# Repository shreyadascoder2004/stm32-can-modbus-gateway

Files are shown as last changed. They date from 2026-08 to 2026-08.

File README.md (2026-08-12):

# STM32 CAN–Modbus Industrial Gateway

A 4-layer STM32-based industrial protocol gateway that bridges RS-485/Modbus-RTU
networks with CAN bus networks — designed end-to-end from schematic to PCB layout
in KiCad, with C firmware handling real-time protocol translation.

## Why this exists

Industrial factory floors often run a mix of legacy RS-485/Modbus-RTU equipment
(sensors, PLCs, HMIs) and newer CAN-based nodes (motor controllers, automotive-grade
modules). This gateway lets a Modbus master (PC, PLC, SCADA system) read and write
values on CAN-based devices without either side needing to natively support the
other's protocol — the same role commercial gateways (e.g. Moxa, Advantech) fill
in real deployments.

## How it works

1. A Modbus master sends a request (Read Holding Registers / Write Single Register)
   over RS-485
2. The STM32 receives it via UART, validates the frame (CRC16), and parses the
   register address and value
3. A lookup table maps the Modbus register to a CAN ID
4. The STM32 sends the corresponding CAN frame onto the bus
5. A CAN node responds; the STM32 receives it, maps it back to a Modbus register,
   and replies to the master over RS-485

USB is reserved for local configuration/debug access.

## Hardware

- **MCU**: STM32F407VET6 (LQFP100)
- **Power**: 24V DC input → TPS54233 buck (5V) → AP1117-33 LDO (3.3V)
- **RS-485**: MAX485E transceiver, jumper-selectable termination, fail-safe biasing
- **CAN**: SN65HVD230 transceiver, jumper-selectable 120Ω termination
- **Board**: 4-layer stackup (Signal / GND plane / 3V3 plane / Signal), designed
  in KiCad — schematic, footprint assignment, and layout completed with dedicated
  ground and power planes

See `/hardware` for the full KiCad project.

## Firmware

Written in C using the STM32 HAL, structured so the protocol logic is
hardware-independent and separately testable:

- `modbus_crc.c` — Modbus CRC16 checksum
- `modbus_parser.c` — Modbus RTU frame parsing and response building
- `can_mapping.c` — Modbus register ↔ CAN ID lookup table
- `main.c` — HAL integration: UART receive interrupt, CAN filter/notification
  setup, and the gateway's main translation loop

Clock tree: 8MHz HSE crystal → PLL → 168MHz SYSCLK, with CAN bus timing configured
for 500kbps on the 42MHz APB1 peripheral clock.

See `/firmware` for the full STM32CubeIDE project.

## Status

- Schematic: complete, ERC-clean
- PCB layout: components placed, 4-layer stackup and plane pours complete,
  routing in progress
- Firmware: compiles cleanly against the current pin mapping; logic modules
  (CRC, frame parsing, ID mapping) are hardware-independent and unit-testable
  on a PC
- Hardware validation: pending PCB fabrication and assembly — no physical
  board has been tested yet

## Build instructions

**Hardware**: open `hardware/*.kicad_pro` in KiCad 8+

**Firmware**: open `firmware/` as an existing project in STM32CubeIDE,
or import via *File → Open Projects from File System*

## License

MIT

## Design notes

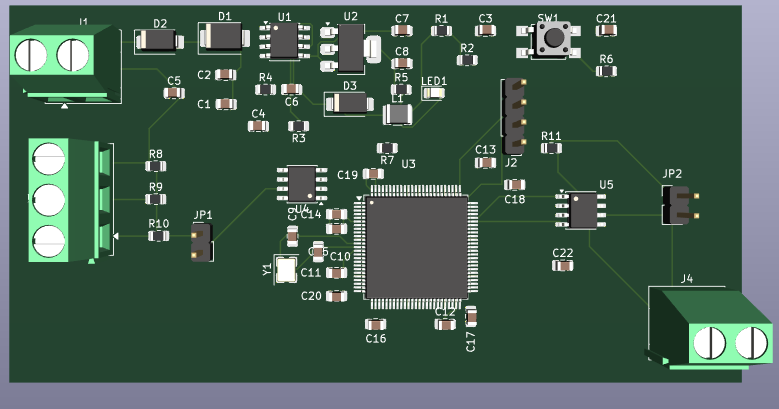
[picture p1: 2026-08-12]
Screenshot 2026-08-13 013130.png

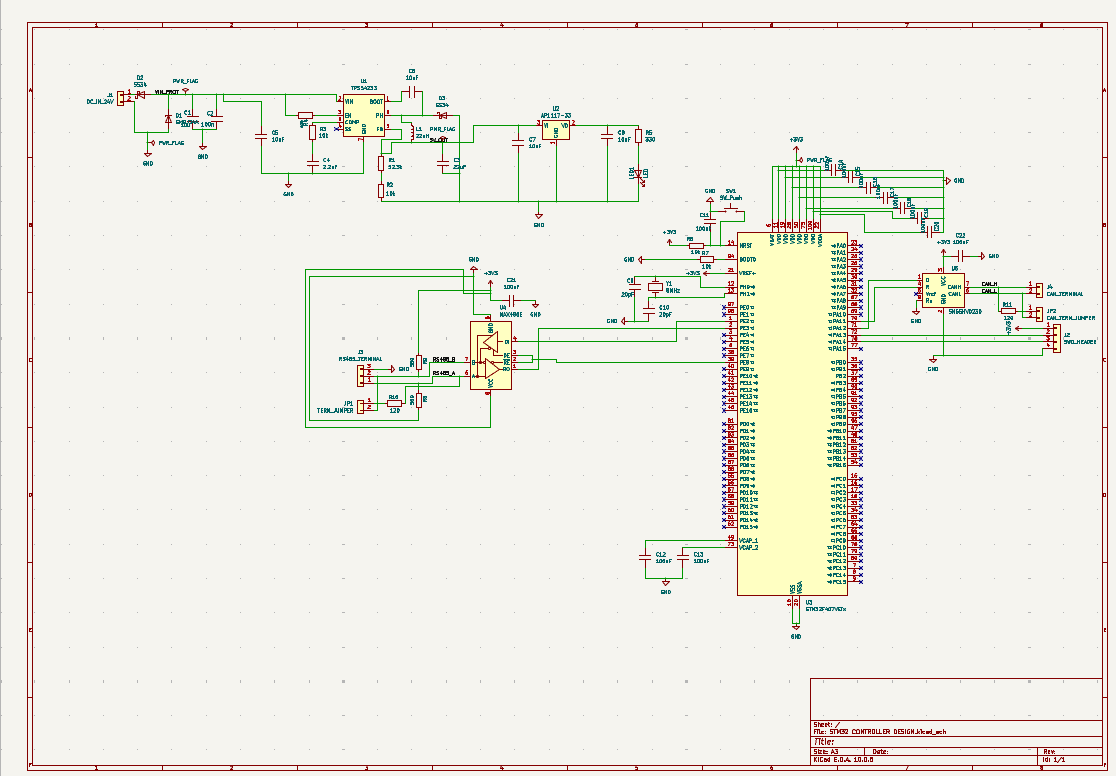
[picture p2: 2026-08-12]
Screenshot 2026-08-13 012855.png

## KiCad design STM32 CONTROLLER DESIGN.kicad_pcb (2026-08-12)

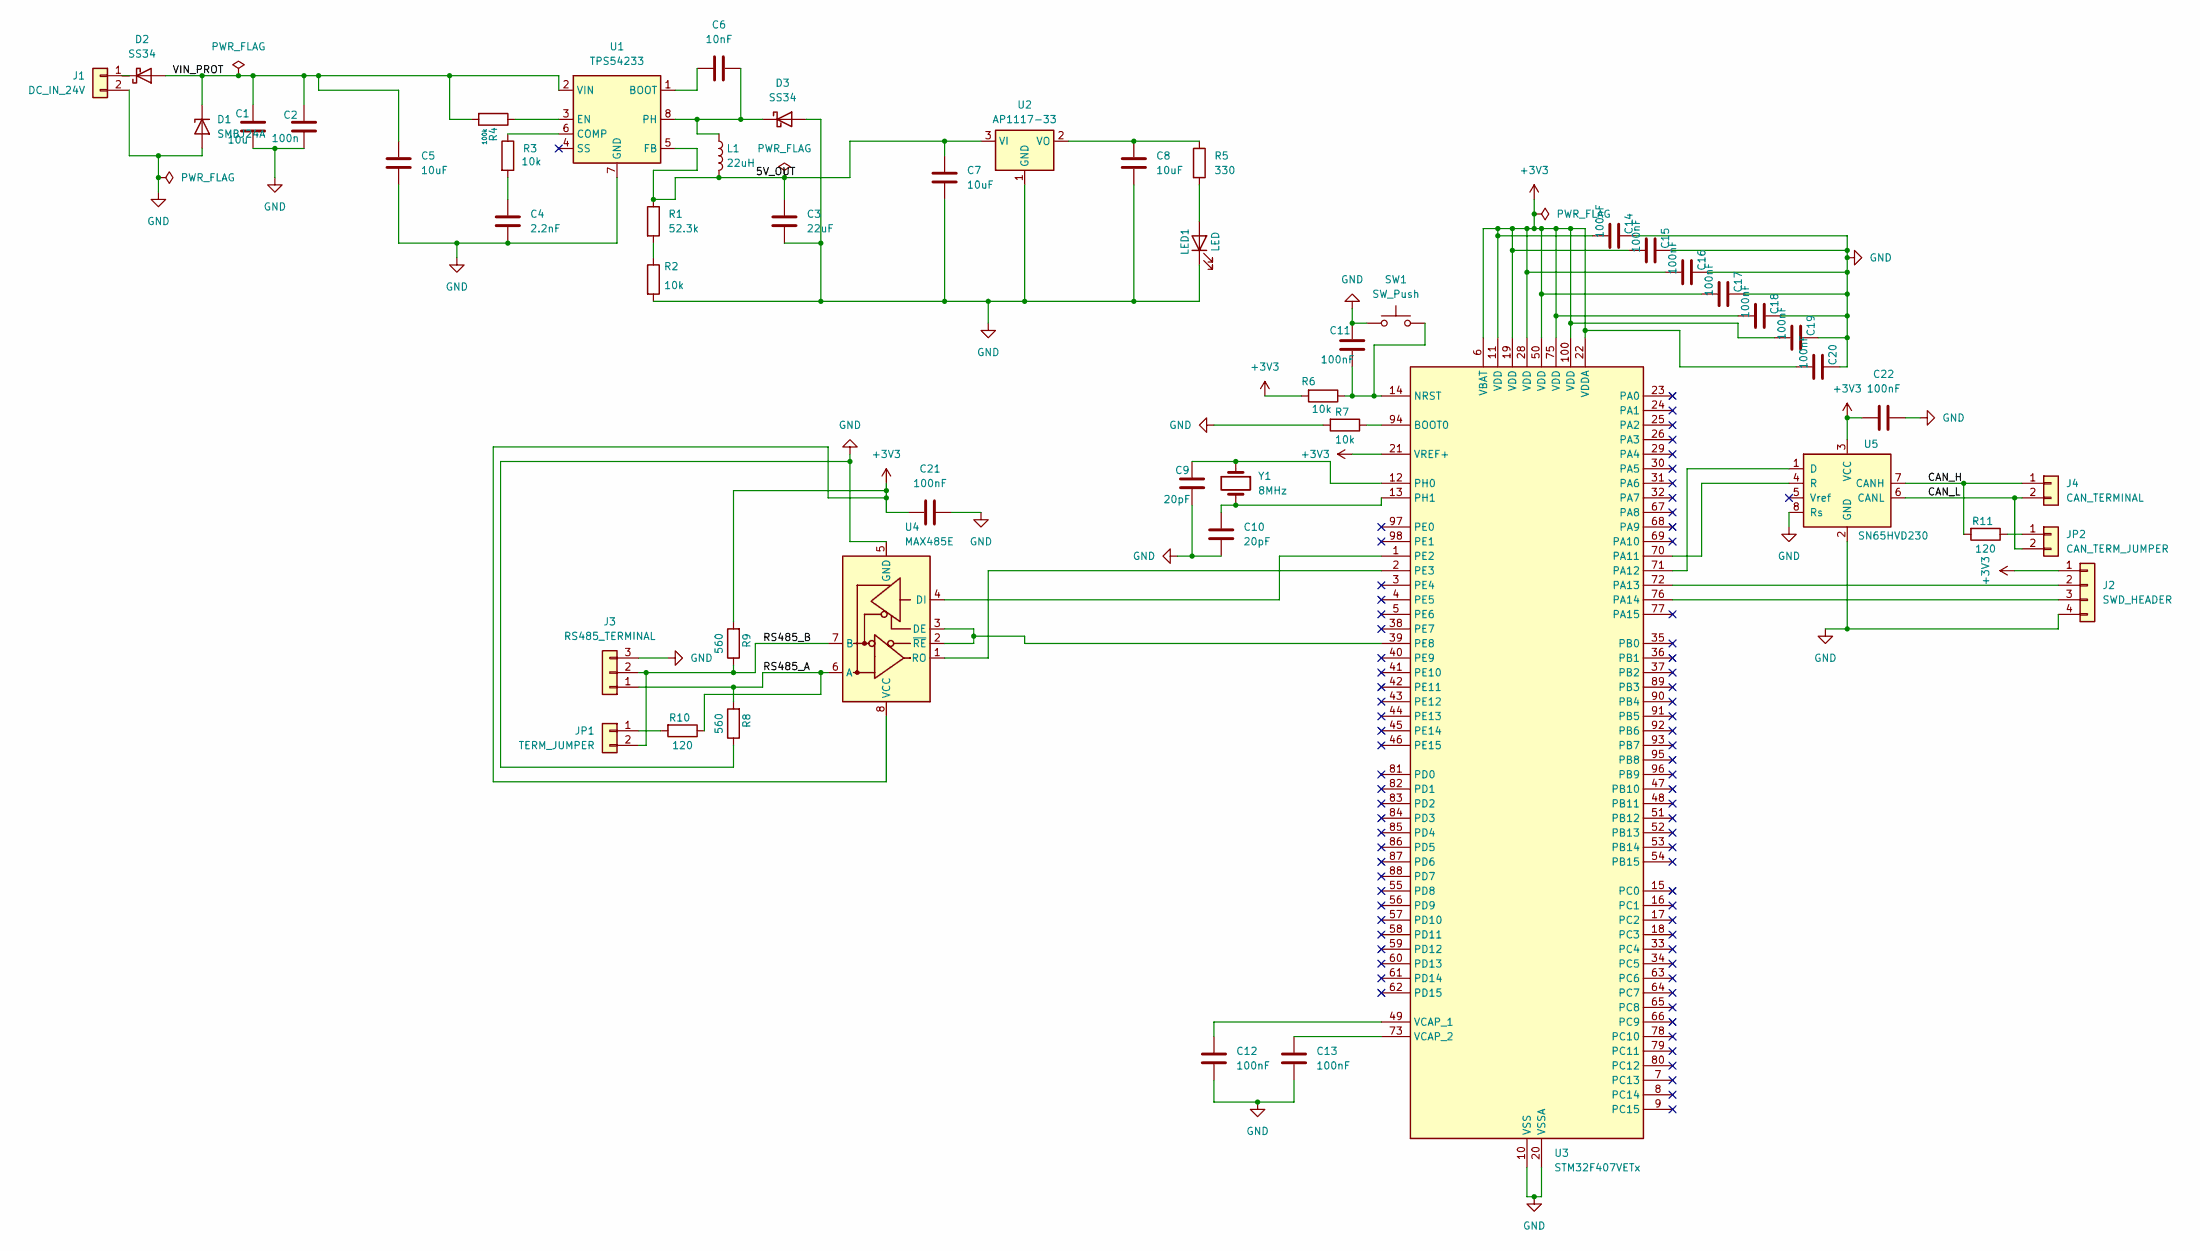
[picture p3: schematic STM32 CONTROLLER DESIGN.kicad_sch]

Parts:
C1: 10u; C_0805_2012Metric
C2: 100n; C_0805_2012Metric
C3: 22uF; C_0805_2012Metric
C4: 2.2nF; C_0805_2012Metric
C5, C7, C8: 10uF; C_0805_2012Metric
C6: 10nF; C_0805_2012Metric
C9, C10: 20pF; C_0805_2012Metric
C11, C12, C13, C14, C15, C16, C17, C18, C19, C20, C21, C22: 100nF; C_0805_2012Metric
D1: SMBJ24A; D_SMB
D2, D3: SS34; D_SMA
J1: DC_IN_24V; TerminalBlock_Phoenix_MKDS-1,5-2-5.08_1x02_P5.08mm_Horizont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
J2: SWD_HEADER; PinHeader_1x04_P2.54mm_Vertical
J3: RS485_TERMINAL; TerminalBlock_Phoenix_MKDS-1,5-3_1x03_P5.00mm_Horizontal
J4: CAN_TERMINAL; TerminalBlock_Phoenix_MKDS-1,5-2-5.08_1x02_P5.08mm_Horizont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
JP1: TERM_JUMPER; PinHeader_1x02_P2.54mm_Vertical
JP2: CAN_TERM_JUMPER; PinHeader_1x02_P2.54mm_Vertical
L1: 22uH; L_1210_3225Metric
LED1: LED; LED_0805_2012Metric
R1: 52.3k; R_0805_2012Metric
R2, R3, R6, R7: 10k; R_0805_2012Metric
R4: 100k; R_0805_2012Metric
R5: 330; R_0805_2012Metric
R8, R9: 560; R_0805_2012Metric
R10, R11: 120; R_0805_2012Metric
SW1: SW_Push; SW_SPST_TL3305A
U1: TPS54233; SOIC-8_3.9x4.9mm_P1.27mm
U2: AP1117-33; SOT-223-3_TabPin2
U3: STM32F407VETx; LQFP-100_14x14mm_P0.5mm
U4: MAX485E; SOIC-8_3.9x4.9mm_P1.27mm
U5: SN65HVD230; SOIC-8_3.9x4.9mm_P1.27mm
Y1: 8MHz; Crystal_SMD_3225-4Pin_3.2x2.5mm

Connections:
+3V3: C14.2, C15.2, C16.2, C17.2, C18.2, C19.2, C20.2, C21.2, C22.2, J2.1, R6.2, R9.2, U3.6 (VBAT), U3.11 (VDD), U3.19 (VDD), U3.21 (VREF+), U3.22 (VDDA), U3.28 (VDD), U3.50 (VDD), U3.75 (VDD), U3.100 (VDD), U4.8 (VCC), U5.3 (VCC)
/5V_OUT: C3.1, C7.1, L1.2, R1.1, U1.5 (FB), U2.3 (VI)
/CAN_H: J4.1, R11.2, U5.7 (CANH)
/CAN_L: J4.2, JP2.2, U5.6 (CANL)
/RS485_A: J3.1, R8.2, R10.1, U4.6 (A)
/RS485_B: J3.2, JP1.2, R9.1, U4.7 (B)
/VIN_PROT: C1.1, C2.1, C5.1, D1.1 (K), D2.2 (A), R4.2, U1.2 (VIN)
GND: C1.2, C2.2, C3.2, C4.2, C5.2, C7.2, C8.2, C9.2, C10.2, C11.1, C12.2, C13.2, C14.1, C15.1, C16.1, C17.1, C18.1, C19.1, C20.1, C21.1, C22.1, D1.2 (A), D3.2 (A), J1.2, J2.4, J3.3, LED1.1 (K), R2.2, R7.2, R8.1, SW1.1, U1.7 (GND), U2.1 (GND), U3.10 (VSS), U3.20 (VSSA), U3.27 (VSS), U3.74 (VSS), U3.99 (VSS), U4.5 (GND), U5.2 (GND), U5.8 (Rs)
unnamed: C4.1, R3.2
unnamed: D2.1 (K), J1.1
unnamed: C6.1, D3.1 (K), L1.1, U1.8 (PH)
unnamed: J2.2, U3.72 (PA13)
unnamed: J2.3, U3.76 (PA14)
unnamed: JP1.1, R10.2
unnamed: JP2.1, R11.1
unnamed: LED1.2 (A), R5.2
unnamed: R1.2, R2.1
unnamed: C6.2, U1.1 (BOOT)
unnamed: R3.1, U1.6 (COMP)
unnamed: R4.1, U1.3 (EN)
unnamed: C8.1, R5.1, U2.2 (VO)
unnamed: R7.1, U3.94 (BOOT0)
unnamed: C11.2, R6.1, SW1.2, U3.14 (NRST)
unnamed: U3.70 (PA11), U5.4 (R)
unnamed: U3.71 (PA12), U5.1 (D)
unnamed: U3.1 (PE2), U4.4 (DI)
unnamed: U3.2 (PE3), U4.1 (RO)
unnamed: U3.39 (PE8), U4.2 (~RE), U4.3 (DE)
unnamed: C9.1, U3.12 (PH0), Y1.1
unnamed: C10.1, U3.13 (PH1), Y1.2
unnamed: C12.1, U3.49 (VCAP_1)
unnamed: C13.1, U3.73 (VCAP_2)

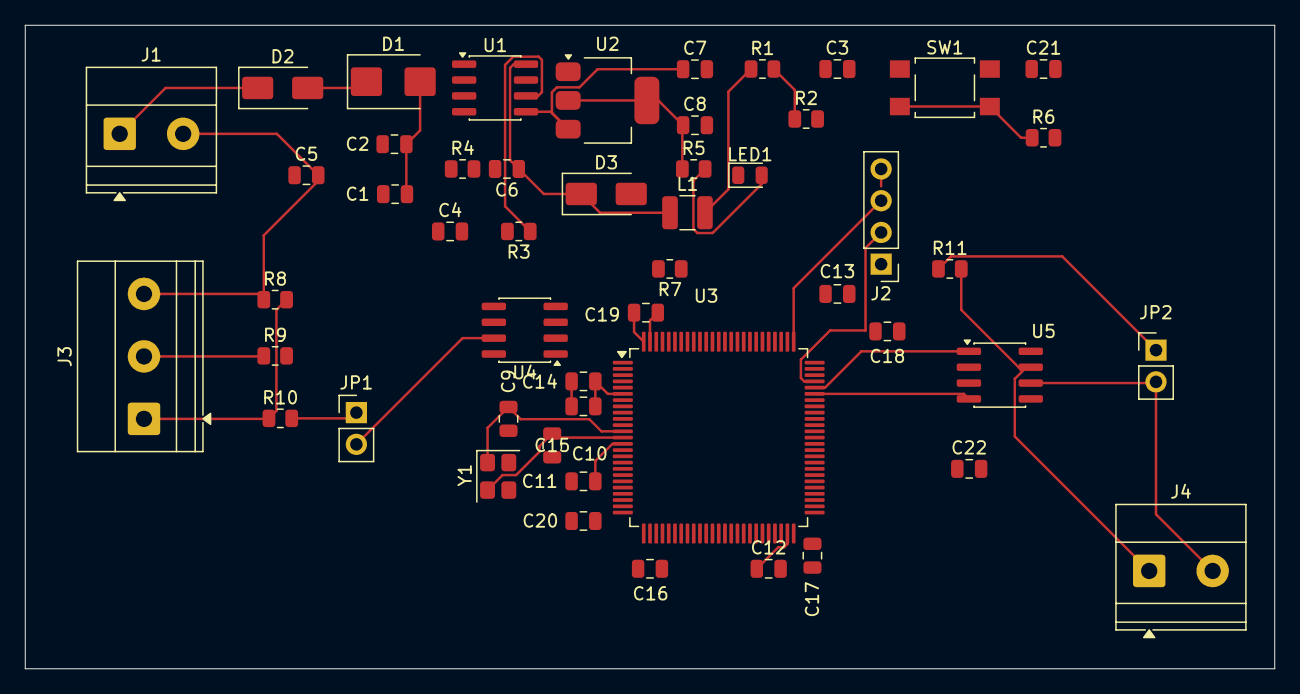
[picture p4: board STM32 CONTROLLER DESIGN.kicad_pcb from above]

Board: 4 copper layers, 100.0 x 51.5 mm, 51 parts (0 on the bottom side), 32 nets.

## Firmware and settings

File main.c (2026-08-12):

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
/* Includes ------------------------------------------------------------------*/
#include "main.h"

/* USER CODE BEGIN Includes */
#include "modbus_crc.h"
#include "modbus_parser.h"
#include "can_mapping.h"
#include <stdbool.h>
/* USER CODE END Includes */

CAN_HandleTypeDef hcan1;

UART_HandleTypeDef huart2;

/* USER CODE BEGIN PV */
uint8_t rx_byte;
uint8_t modbus_rx_buffer[64];
volatile uint16_t modbus_rx_index = 0;
volatile bool modbus_frame_ready = false;

CAN_TxHeaderTypeDef can_tx_header;
CAN_RxHeaderTypeDef can_rx_header;
uint8_t can_tx_data[8];
uint8_t can_rx_data[8];
uint32_t can_tx_mailbox;
/* USER CODE END PV */

void SystemClock_Config(void);
static void MX_GPIO_Init(void);
static void MX_CAN1_Init(void);
static void MX_USART2_UART_Init(void);
/**
  * @brief  The application entry point.
  * @retval int
  */
int main(void)
{

  /* MCU Configuration--------------------------------------------------------*/

  /* Reset of all peripherals, Initializes the Flash interface and the Systick. */
  HAL_Init();

  /* Configure the system clock */
  SystemClock_Config();

  /* Initialize all configured peripherals */
  MX_GPIO_Init();
  MX_CAN1_Init();
  MX_USART2_UART_Init();

  /* USER CODE BEGIN 2 */
  HAL_UART_Receive_IT(&huart2, &rx_byte, 1);

  CAN_FilterTypeDef can_filter;
  can_filter.FilterBank = 0;
  can_filter.FilterMode = CAN_FILTERMODE_IDMASK;
  can_filter.FilterScale = CAN_FILTERSCALE_32BIT;
  can_filter.FilterIdHigh = 0x0000;
  can_filter.FilterIdLow = 0x0000;
  can_filter.FilterMaskIdHigh = 0x0000;
  can_filter.FilterMaskIdLow = 0x0000;
  can_filter.FilterFIFOAssignment = CAN_RX_FIFO0;
  can_filter.FilterActivation = ENABLE;
  HAL_CAN_ConfigFilter(&hcan1, &can_filter);

  HAL_CAN_Start(&hcan1);
  HAL_CAN_ActivateNotification(&hcan1, CAN_IT_RX_FIFO0_MSG_PENDING);
  /* USER CODE END 2 */

  /* Infinite loop */
  /* USER CODE BEGIN WHILE */
  while (1)
  {
    if (modbus_frame_ready)
    {
        modbus_frame_ready = false;

        ModbusRequest req;
        if (modbus_parse_request(modbus_rx_buffer, modbus_rx_index, &req))
        {
            uint32_t can_id;
            if (can_mapping_lookup(req.register_addr, &can_id))
            {
                can_tx_header.StdId = can_id;
                can_tx_header.IDE = CAN_ID_STD;
                can_tx_header.RTR = CAN_RTR_DATA;
                can_tx_header.DLC = 2;
                can_tx_data[0] = (req.value_or_count >> 8) & 0xFF;
                can_tx_data[1] = req.value_or_count & 0xFF;

                HAL_CAN_AddTxMessage(&hcan1, &can_tx_header, can_tx_data, &can_tx_mailbox);
            }
        }

        modbus_rx_index = 0;
    }

    /* USER CODE END WHILE */

    /* USER CODE BEGIN 3 */
  }
  /* USER CODE END 3 */
}

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
/* USER CODE BEGIN 4 */
void HAL_UART_RxCpltCallback(UART_HandleTypeDef *huart)
{
    if (huart->Instance == USART2)
    {
        if (modbus_rx_index < sizeof(modbus_rx_buffer))
        {
            modbus_rx_buffer[modbus_rx_index++] = rx_byte;
        }

        if (modbus_rx_index >= 8)
        {
            modbus_frame_ready = true;
        }

        HAL_UART_Receive_IT(huart, &rx_byte, 1);
    }
}

void HAL_CAN_RxFifo0MsgPendingCallback(CAN_HandleTypeDef *hcan)
{
    if (HAL_CAN_GetRxMessage(hcan, CAN_RX_FIFO0, &can_rx_header, can_rx_data) == HAL_OK)
    {
        uint16_t modbus_reg;
        if (can_mapping_reverse_lookup(can_rx_header.StdId, &modbus_reg))
        {
            uint16_t received_value = ((uint16_t)can_rx_data[0] << 8) | can_rx_data[1];

            uint8_t response_buf[16];
            uint16_t response_len = modbus_build_read_response(1, &received_value, 1, response_buf);

            HAL_GPIO_WritePin(RS485_DE_GPIO_Port, RS485_DE_Pin, GPIO_PIN_SET);
            HAL_UART_Transmit(&huart2, response_buf, response_len, 100);
            HAL_GPIO_WritePin(RS485_DE_GPIO_Port, RS485_DE_Pin, GPIO_PIN_RESET);
        }
    }
}
/* USER CODE END 4 */
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


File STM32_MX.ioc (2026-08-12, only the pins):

Mcu.UserName=STM32F407VETx
PA11.Signal=CAN1_RX
PA12.Signal=CAN1_TX
PA2.Signal=USART2_TX
PA3.Signal=USART2_RX
PA8.GPIO_Label=RS485_DE
PA8.Signal=GPIO_Output
PH0-OSC_IN.Signal=RCC_OSC_IN
PH1-OSC_OUT.Signal=RCC_OSC_OUT

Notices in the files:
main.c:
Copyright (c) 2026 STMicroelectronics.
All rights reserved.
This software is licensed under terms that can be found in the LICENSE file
